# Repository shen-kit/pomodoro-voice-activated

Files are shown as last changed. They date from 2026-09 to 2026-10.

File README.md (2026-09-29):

# Schematic

## Parts List

- [capacitors](https://www.digikey.com.au/en/products/detail/nextgen-components/0402W105M6R3HI/18677006) 
	- 10nF: [0402B103K500HI](https://www.digikey.com.au/en/products/detail/nextgen-components/0402B103K500HI/22601905)
	- 0.1uF: [0402B104K250HI](https://www.digikey.com.au/en/products/detail/nextgen-components/0402B104K250HI/14670955)
	- 1uF: [0402W105M6R3HI](https://www.digikey.com.au/en/products/detail/nextgen-components/0402W105M6R3HI/18677006), 
	- 4.7uF: [0402W475M6R3HI](https://www.digikey.com.au/en/products/detail/nextgen-components/0402W475M6R3HI/18677043)
	- 10uF: [0402W106M6R3HI](https://www.digikey.com.au/en/products/detail/nextgen-components/0402W106M6R3HI/18677011)
	- footprint: 0402
	- 220uF electrolytic: [Wurth Elektronik 865080245009](https://www.digikey.com.au/en/products/detail/w%C3%BCrth-elektronik/865080245009/5728087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)
	- footprint: 6.6 (dia) x 7.7 (height)
- LEDs: [green](https://www.digikey.com.au/en/products/detail/xinglight/XL-1608PGC-06/25673192) | [red](https://www.digikey.com.au/en/products/detail/xinglight/XL-1608VRC-06/25673309)
	- green: XL-1608PGC-06
    - red: XL-1608VRC-06
	- footprint: 0603
- [schottky diode](PMEG2015EH,115):
	- PMEG2015EH,115
- resistors (CR0603)
	- 330: [CR0603-FX-3300ELF](https://www.digikey.com.au/en/products/detail/bourns-inc/CR0603-FX-3300ELF/3783948)
	- 3.3k: [CR0603-JW-332ELF](https://www.digikey.com.au/en/products/detail/bourns-inc/CR0603-JW-332ELF/3784358)
	- 5.1k: [CR0603-FX-5101ELF](https://www.digikey.com.au/en/products/detail/bourns-inc/CR0603-FX-5101ELF/3784064)
	- 10k: [CR0603-FX-1002ELF](https://www.digikey.com.au/en/products/detail/bourns-inc/CR0603-FX-1002ELF/3593188)
	- 100k: [CR0603-FX-1003ELF](https://www.digikey.com.au/en/products/detail/bourns-inc/CR0603-FX-1003ELF/3593193)
- [push button](https://www.digikey.com.au/en/products/detail/c-k/PTS636SK25SMTR-LFS/10071735)
	- PTS636SK25SMTR LFS
- [usb receptacle](https://au.mouser.com/en/ProductDetail/Same-Sky/UJ20-C-H-G-SMT-1-P16-TR)
	- 179-UJ20CHGSMT1P16TR
- JST PH2.0 connector
- IRLML6402
- APK2112K-3.3
- MCP73831-2-OT
- ESP32-S3-WROOM-1-N16R8

## GPIO Connections

| Function | ESP32-S3 GPIO |
| --- | --- |
| OLED_SDA | 10 |
| OLED_SCL | 9 |
| MIC_SCK | 5 |
| MIC_WS | 6 |
| MIC_SD | 7 |
| ENCODER_A  | 14 |
| ENCODER_B  | 13 |
| ENCODER_SW | 12 |
| LED_DATA | 16 |

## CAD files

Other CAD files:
drafts/pomodoro_draft_mockup.blend

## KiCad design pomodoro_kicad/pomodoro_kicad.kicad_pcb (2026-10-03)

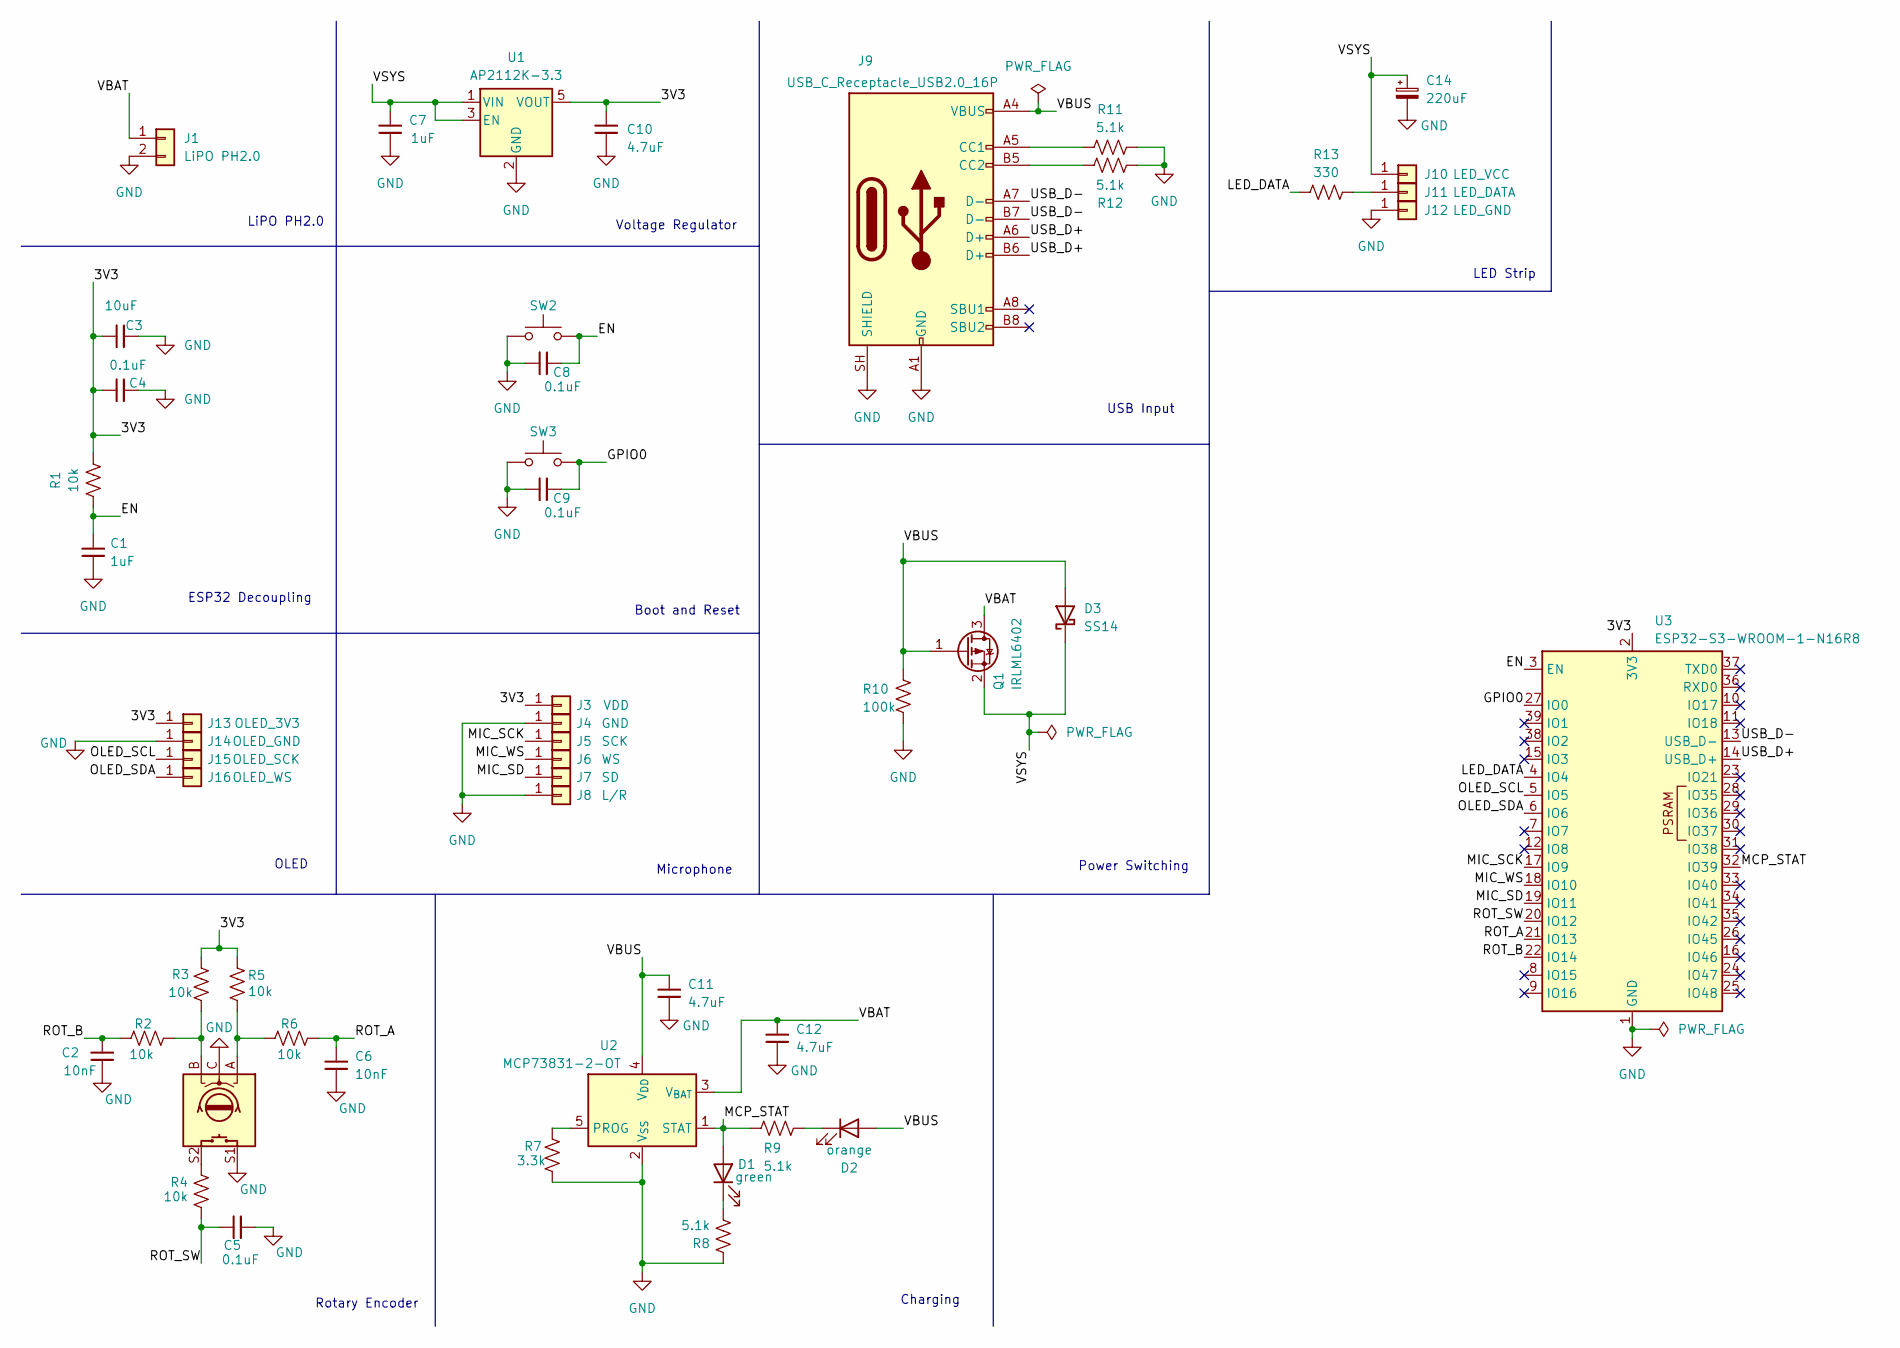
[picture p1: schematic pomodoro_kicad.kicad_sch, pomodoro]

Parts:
C1, C7: 1uF; C_0402_1005Metric
C2, C6: 10nF; C_0402_1005Metric
C3: 10uF; C_0402_1005Metric
C4, C5, C8, C9: 0.1uF; C_0402_1005Metric
C10, C11, C12: 4.7uF; C_0402_1005Metric
C14: 220uF; CP_Elec_6.3x7.7
D1: green; LED_0603_1608Metric
D2: orange; LED_0603_1608Metric
D3: SS14; D_SOD-123F
J1: LiPO PH2.0; JST_PH_S2B-PH-SM4-TB_1x02-1MP_P2.00mm_Horizontal
J3: VDD; TestPoint_THTPad_D2.0mm_Drill1.0mm
J4: GND; TestPoint_THTPad_D2.0mm_Drill1.0mm
J5: SCK; TestPoint_THTPad_D2.0mm_Drill1.0mm
J6: WS; TestPoint_THTPad_D2.0mm_Drill1.0mm
J7: SD; TestPoint_THTPad_D2.0mm_Drill1.0mm
J8: L/R; TestPoint_THTPad_D2.0mm_Drill1.0mm
J9: USB_C_Receptacle_USB2.0_16P; USB_C_Receptacle_HRO_TYPE-C-31-M-12
J10: LED_VCC; TestPoint_THTPad_D2.0mm_Drill1.0mm
J11: LED_DATA; TestPoint_THTPad_D2.0mm_Drill1.0mm
J12: LED_GND; TestPoint_THTPad_D2.0mm_Drill1.0mm
J13: OLED_3V3; TestPoint_THTPad_D2.0mm_Drill1.0mm
J14: OLED_GND; TestPoint_THTPad_D2.0mm_Drill1.0mm
J15: OLED_SCK; TestPoint_THTPad_D2.0mm_Drill1.0mm
J16: OLED_WS; TestPoint_THTPad_D2.0mm_Drill1.0mm
Q1: IRLML6402; SOT-23-3
R1, R2, R3, R4, R5, R6: 10k; R_0603_1608Metric
R7: 3.3k; R_0603_1608Metric
R8, R9, R11, R12: 5.1k; R_0603_1608Metric
R10: 100k; R_0603_1608Metric
R13: 330; R_0603_1608Metric
SW1: RotaryEncoder_Switch; rotaryEncoder
SW2, SW3: SW_Tactile_SPST_NO_Straight_CK_PTS636Sx25SMTRLFS
U1: AP2112K-3.3; SOT-23-5
U2: MCP73831-2-OT; SOT-23-5
U3: ESP32-S3-WROOM-1-N16R8; ESP32-S3-WROOM-1

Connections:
/3V3: C3.1, C4.1, C10.1, J3.1 (Pin_1_1), J13.1 (Pin_1_1), R1.1, R3.1, R5.1, U1.5 (VOUT), U3.2 (3V3)
/EN: C1.1, C8.1, R1.2, SW2.2, U3.3 (EN)
/GPIO0: C9.1, SW3.2, U3.27 (IO0)
/LED_DATA: R13.2, U3.4 (IO4)
/MCP_STAT: D1.2 (A), R9.1, U2.1 (STAT), U3.32 (IO39)
/MIC_SCK: J5.1 (Pin_1_1), U3.17 (IO9)
/MIC_SD: J7.1 (Pin_1_1), U3.19 (IO11)
/MIC_WS: J6.1 (Pin_1_1), U3.18 (IO10)
/OLED_SCL: J15.1 (Pin_1_1), U3.5 (IO5)
/OLED_SDA: J16.1 (Pin_1_1), U3.6 (IO6)
/ROT_A: C6.2, R6.1, U3.21 (IO13)
/ROT_B: C2.2, R2.1, U3.22 (IO14)
/ROT_SW: C5.2, R4.1, U3.20 (IO12)
/USB_D+: J9.A6 (D+), J9.B6 (D+), U3.14 (USB_D+)
/USB_D-: J9.A7 (D-), J9.B7 (D-), U3.13 (USB_D-)
/VBAT: C12.1, J1.1, Q1.3 (D), U2.3 (V_{BAT})
/VBUS: C11.1, D2.2 (A), D3.2 (A), J9.A4 (VBUS), J9.A9 (VBUS), J9.B4 (VBUS), J9.B9 (VBUS), Q1.1 (G), R10.1, U2.4 (V_{DD})
/VSYS: C7.1, C14.1, D3.1 (K), J10.1 (Pin_1_1), Q1.2 (S), U1.1 (VIN), U1.3 (EN)
GND: C1.2, C2.1, C3.2, C4.2, C5.1, C6.1, C7.2, C8.2, C9.2, C10.2, C11.2, C12.2, C14.2, J1.2, J4.1 (Pin_1_1), J8.1 (Pin_1_1), J9.A1 (GND), J9.A12 (GND), J9.B1 (GND), J9.B12 (GND), J9.SH (SHIELD), J12.1 (Pin_1_1), J14.1 (Pin_1_1), R7.1, R8.2, R10.2, R11.1, R12.2, SW1.C, SW1.S1, SW2.1, SW3.1, U1.2 (GND), U2.2 (V_{SS}), U3.1 (GND), U3.40 (GND), U3.41 (GND)
unnamed: D1.1 (K), R8.1
unnamed: D2.1 (K), R9.2
unnamed: J9.A5 (CC1), R11.2
unnamed: J9.B5 (CC2), R12.1
unnamed: J11.1 (Pin_1_1), R13.1
unnamed: R2.2, R3.2, SW1.B
unnamed: R4.2, SW1.S2
unnamed: R5.2, R6.2, SW1.A
unnamed: R7.2, U2.5 (PROG)

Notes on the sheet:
Power Switching
LED Strip
OLED
Voltage Regulator
Charging
Microphone
LiPO PH2.0
ESP32 Decoupling
USB Input
Rotary Encoder
Boot and Reset

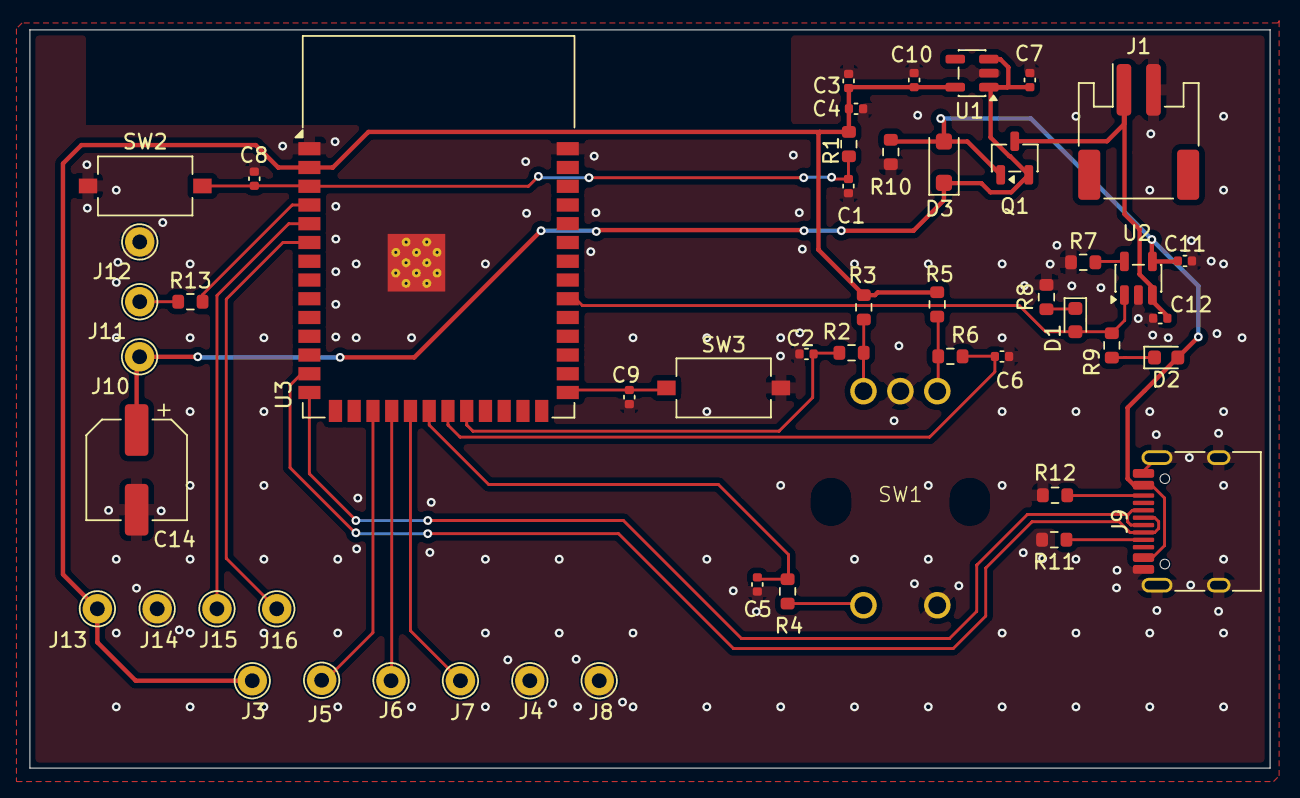
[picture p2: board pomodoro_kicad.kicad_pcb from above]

Board: 2 copper layers, 84.0 x 50.0 mm, 51 parts (0 on the bottom side), 28 nets.

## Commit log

2026-09-27 Schematic: MCU power, reset, boot
    [pomodoro_kicad.kicad_pcb, pomodoro_kicad.kicad_sch]
2026-09-27 Datasheet: Add ESP32-S3 devkit
2026-09-27 Schematic: Add OLED and rotary encoder
    [pomodoro_kicad.kicad_sch]
2026-09-29 Finish schematic, assign footprints, draft PCB layout
    [pomodoro_kicad.kicad_pcb, pomodoro_kicad.kicad_sch]
2026-09-29 Assign footprints with actual parts
    assigned:
    - capacitors
    - LEDs
    - diode
    - resistors
    - push button
    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
    [pomodoro_kicad.kicad_pcb, pomodoro_kicad.kicad_sch]
2026-10-03 Create blender mockup
    [pomodoro_draft_mockup.blend]
2026-10-03 Finish assigning footprints
    [pomodoro_kicad.kicad_sch]
2026-10-03 First PCB layout not correct positions
    [pomodoro_kicad.kicad_pcb]
2026-10-03 Route PCB and update schematic pins for better connections
    [pomodoro_kicad.kicad_pcb, pomodoro_kicad.kicad_sch]
2026-10-03 Add stitching vias with 5mm spacing
    [pomodoro_kicad.kicad_pcb]
